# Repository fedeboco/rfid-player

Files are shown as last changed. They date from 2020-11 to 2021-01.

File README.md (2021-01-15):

# RFID Music Player

System that provides an RFID card reader in order to select an album or track in an SD card, avoiding use of buttons or hard to use interfaces for elder people.

- Braille Compatibility.
- Designed for people with advanced age or hearing loss.
- SD Card support. 
- High volume. Volume control.
- Track and album control.
- Easy to setup new RFID cards by custom setup interface.

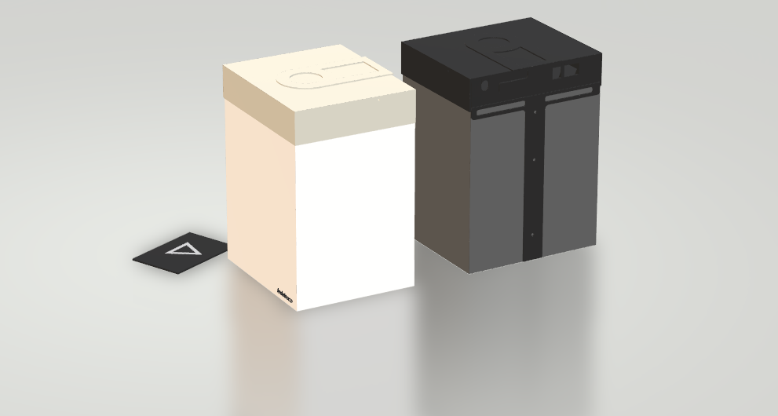
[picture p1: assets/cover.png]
![]()<p align="center">

## PCB

Custom PCB design for hand printing and soldering.
  
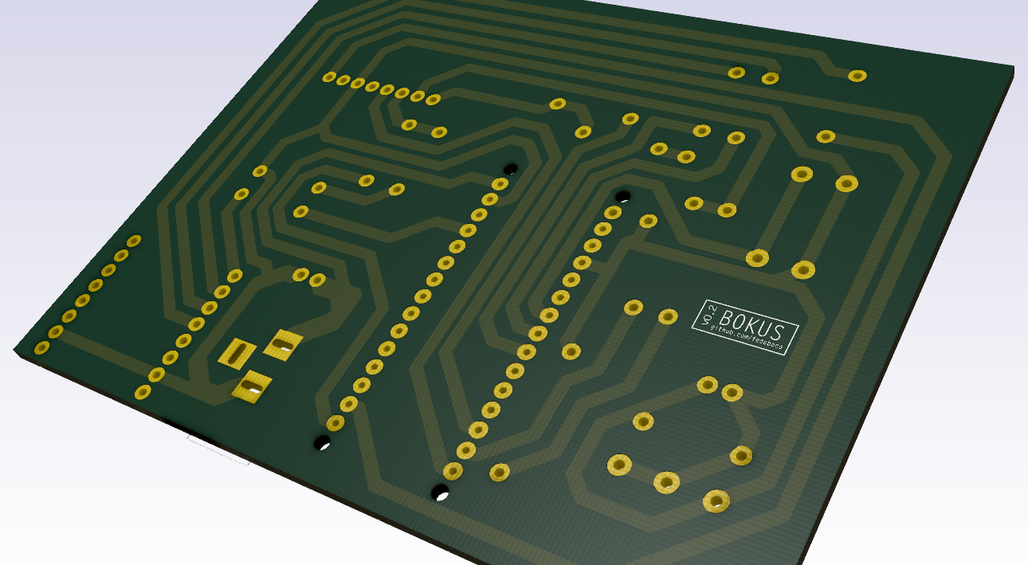
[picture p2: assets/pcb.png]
![]()<p align="center">
  
## Schematic

Custom circuit design.
  
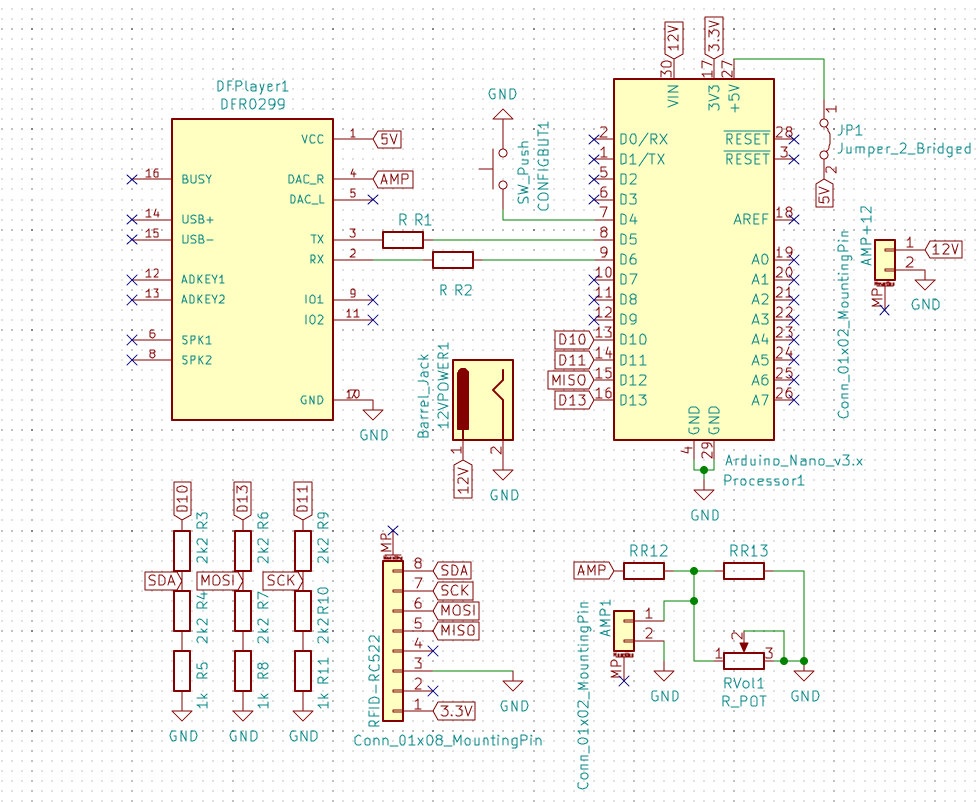
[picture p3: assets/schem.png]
![]()<p align="center">
  
## 3D Parts

Custom 3D printed enclosure for safe circuit install.

### Top
  
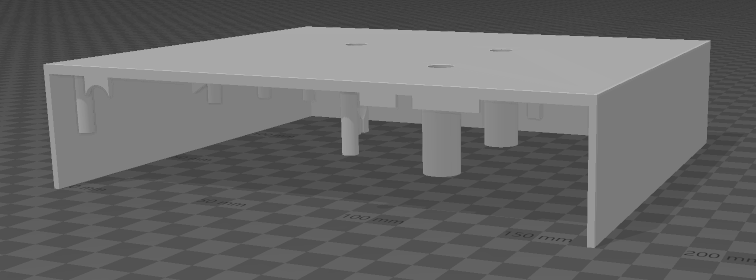
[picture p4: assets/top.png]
![]()<p align="center">
  
### Bot  
  
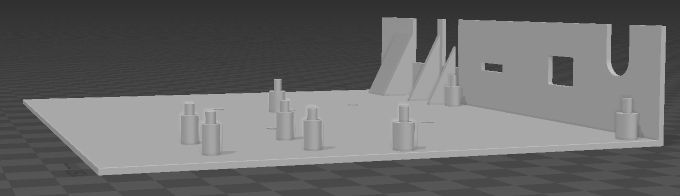
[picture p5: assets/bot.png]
![]()<p align="center">
  
### Back

![]()<p align="center">
  
### Decor

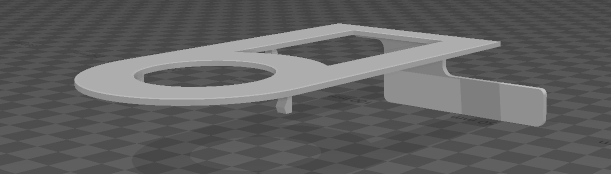
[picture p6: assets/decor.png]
![]()<p align="center">

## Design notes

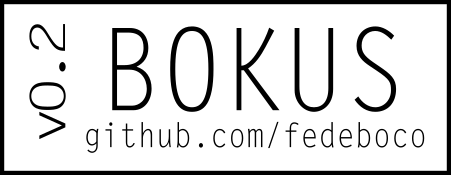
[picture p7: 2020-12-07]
board/rfid-player/label.png

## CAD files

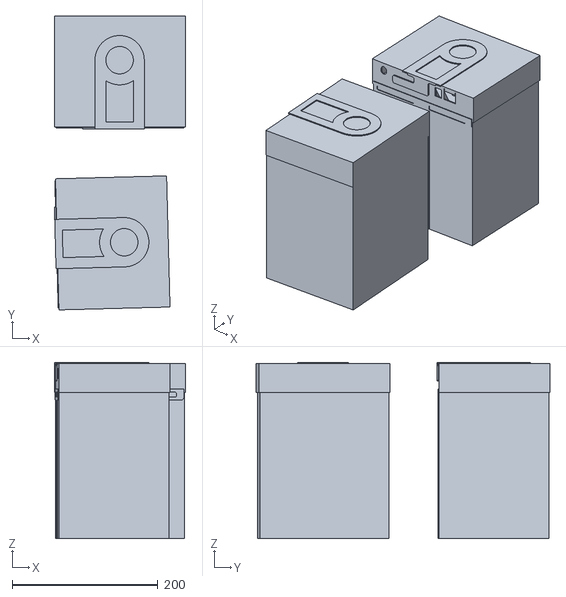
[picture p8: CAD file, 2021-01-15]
stl/complete.stl
180.0 x 403.2 x 241.5

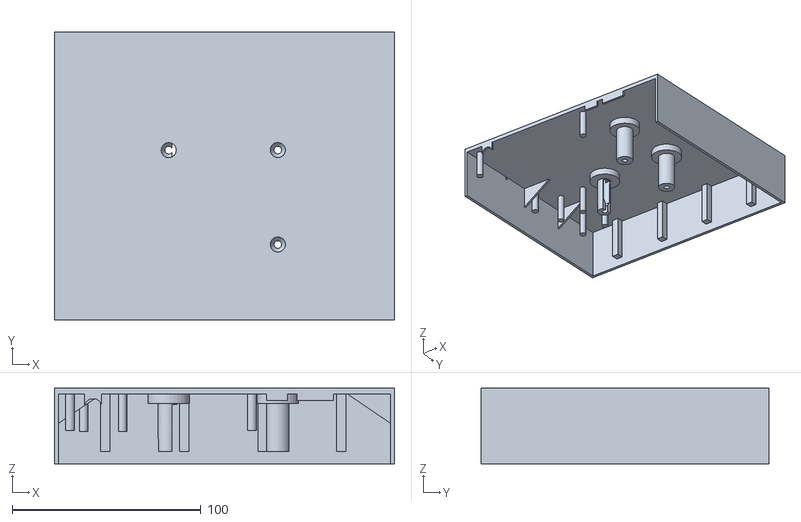
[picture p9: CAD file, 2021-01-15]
stl/top.stl
180.0 x 152.5 x 40.0

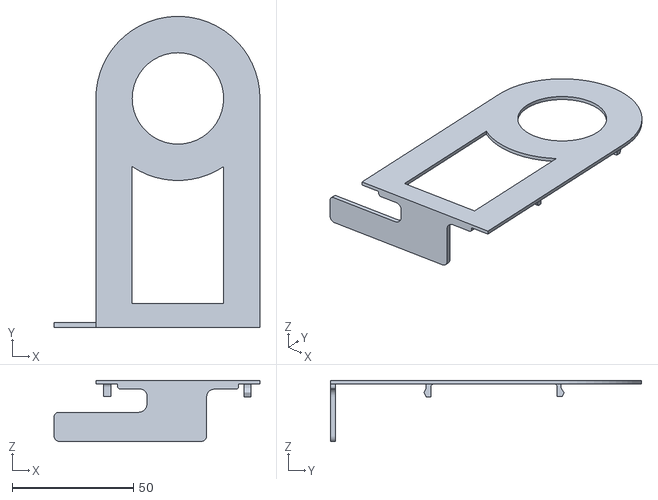
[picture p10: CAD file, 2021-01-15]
stl/decor.stl
85.0 x 128.3 x 25.2

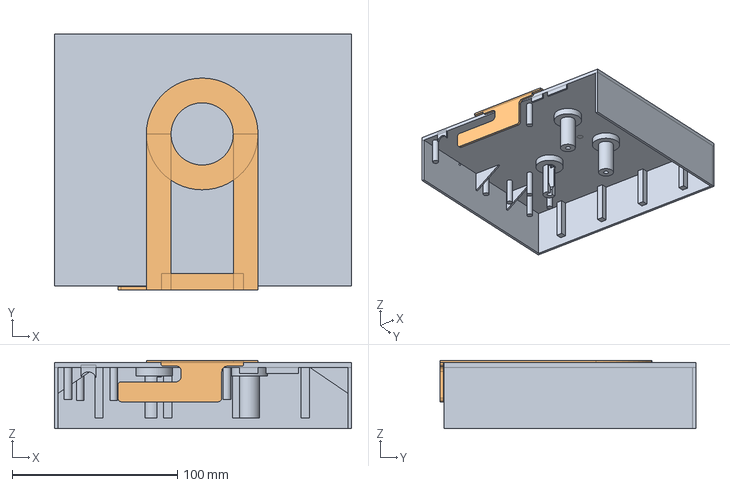
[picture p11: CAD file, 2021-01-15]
stl/topbox.FCStd
180.0 x 155.0 x 41.5 mm
Top
Decor

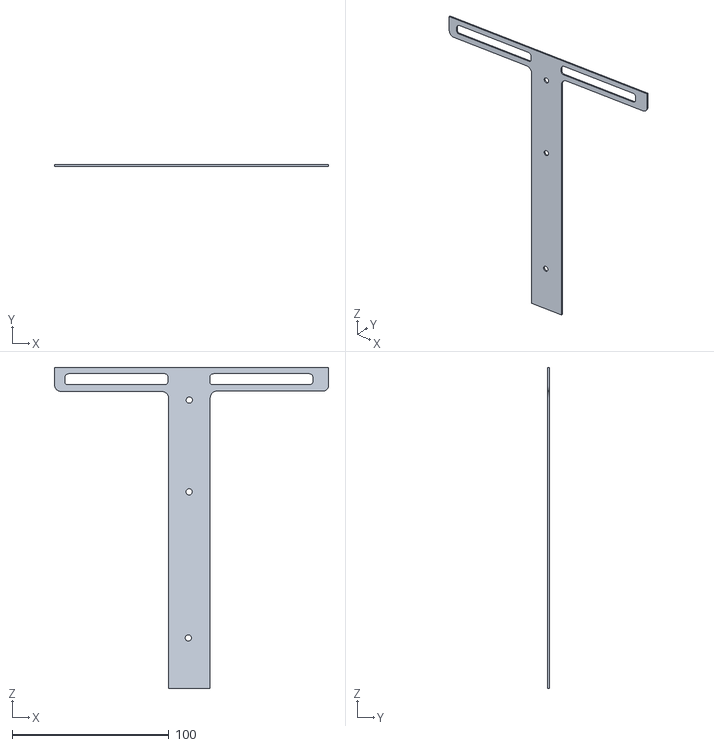
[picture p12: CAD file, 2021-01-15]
stl/back.stl
175.0 x 1.00 x 205.0

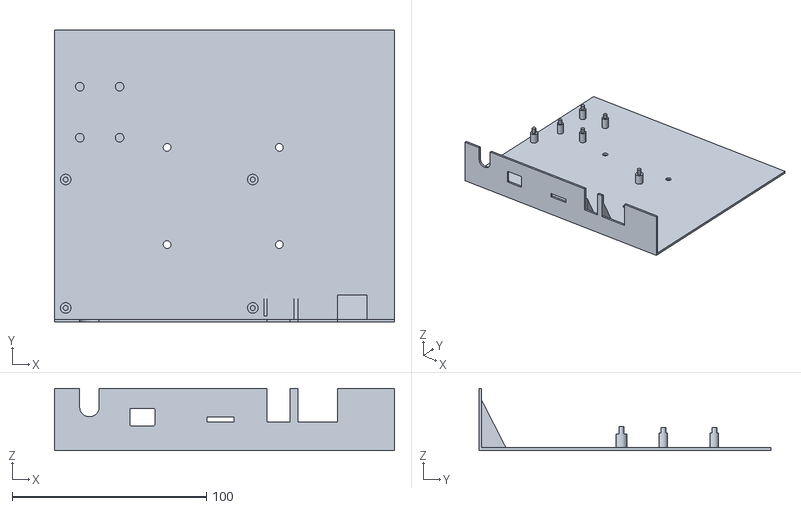
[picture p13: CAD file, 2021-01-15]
stl/bot.stl
175.0 x 150.5 x 32.0

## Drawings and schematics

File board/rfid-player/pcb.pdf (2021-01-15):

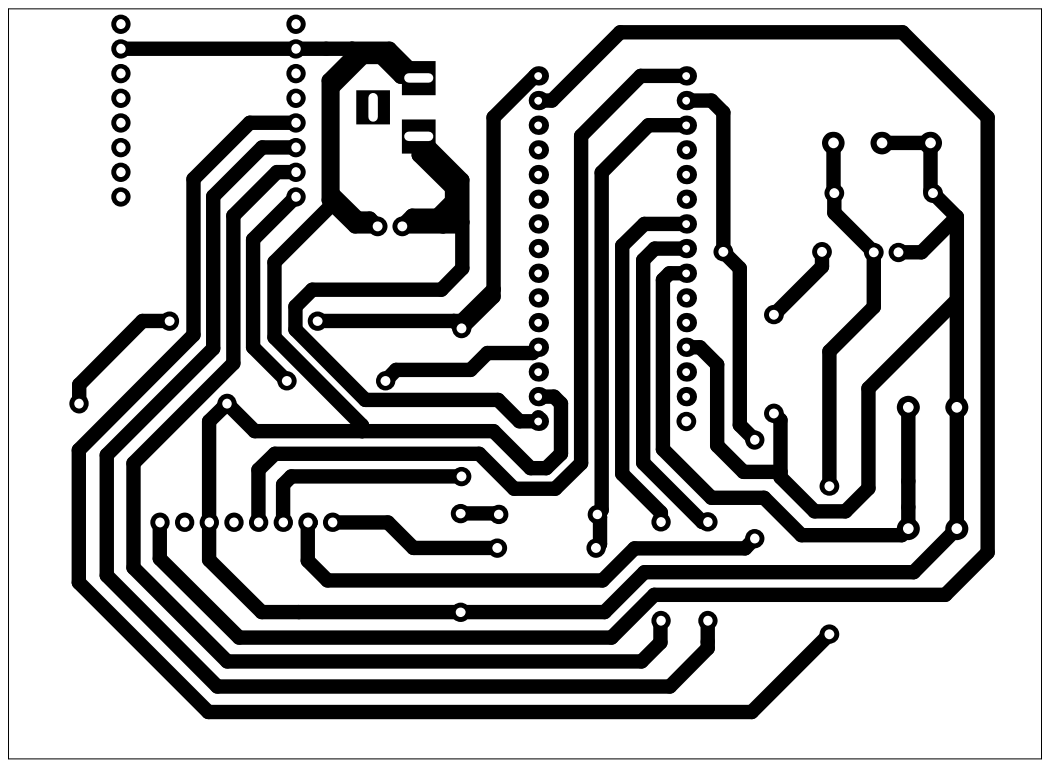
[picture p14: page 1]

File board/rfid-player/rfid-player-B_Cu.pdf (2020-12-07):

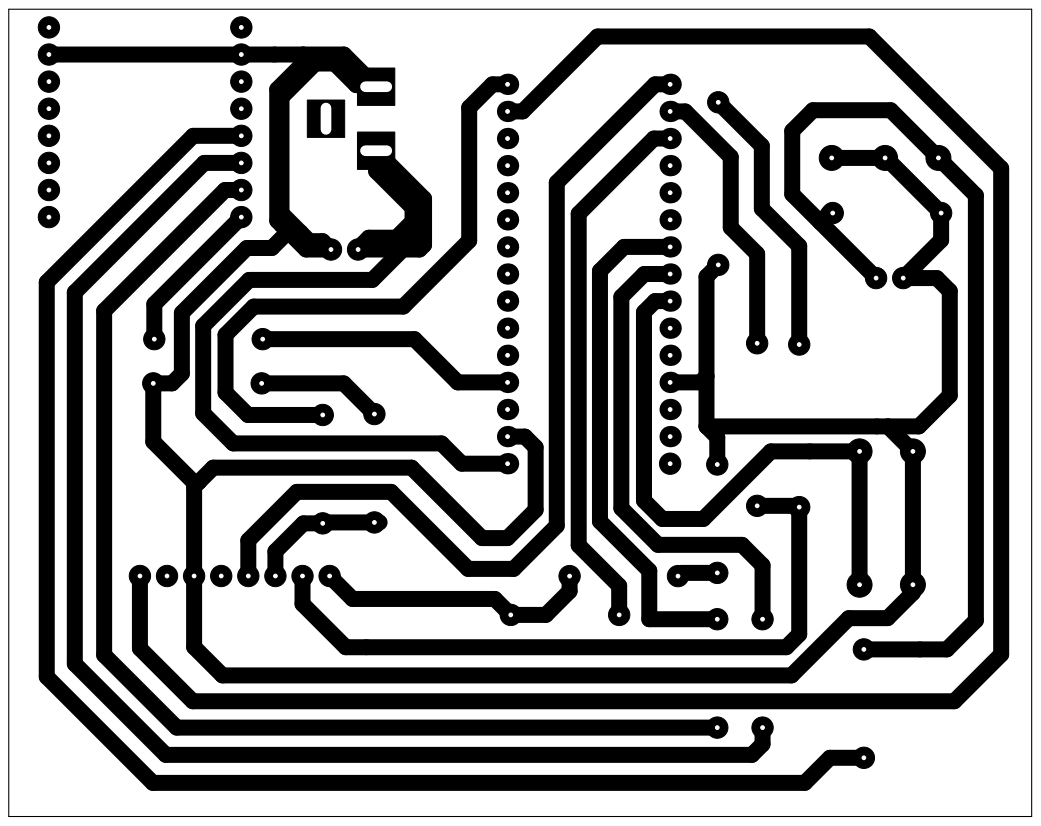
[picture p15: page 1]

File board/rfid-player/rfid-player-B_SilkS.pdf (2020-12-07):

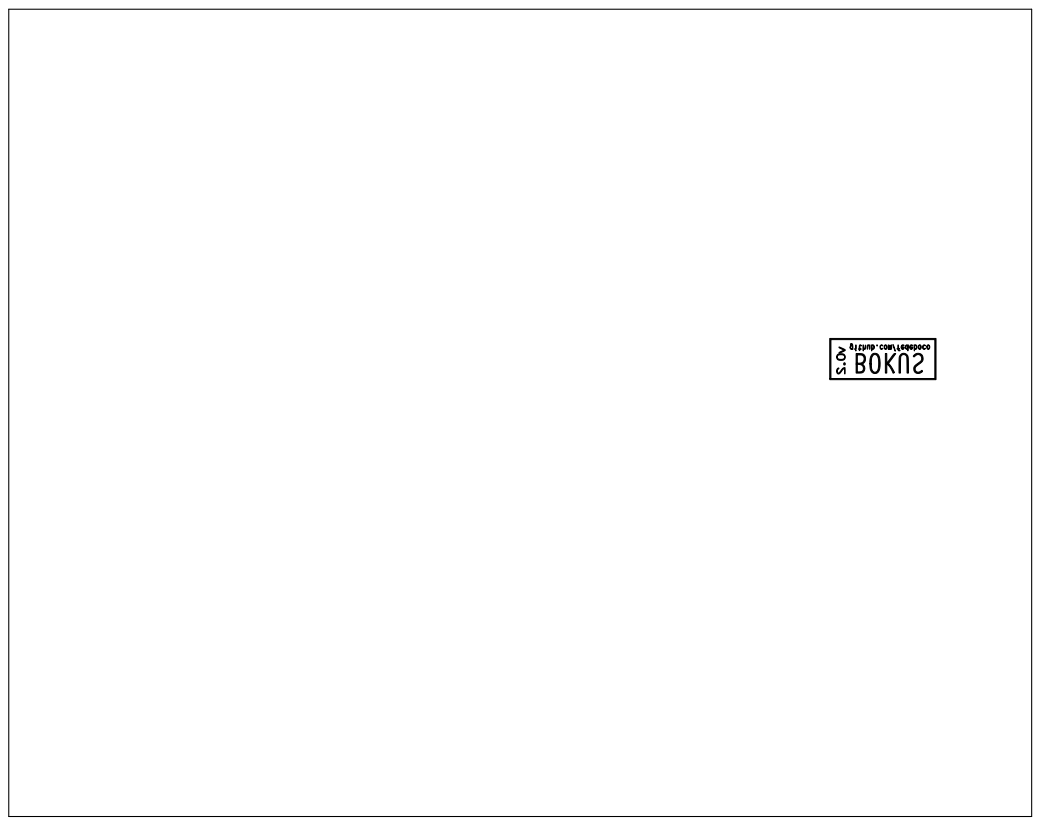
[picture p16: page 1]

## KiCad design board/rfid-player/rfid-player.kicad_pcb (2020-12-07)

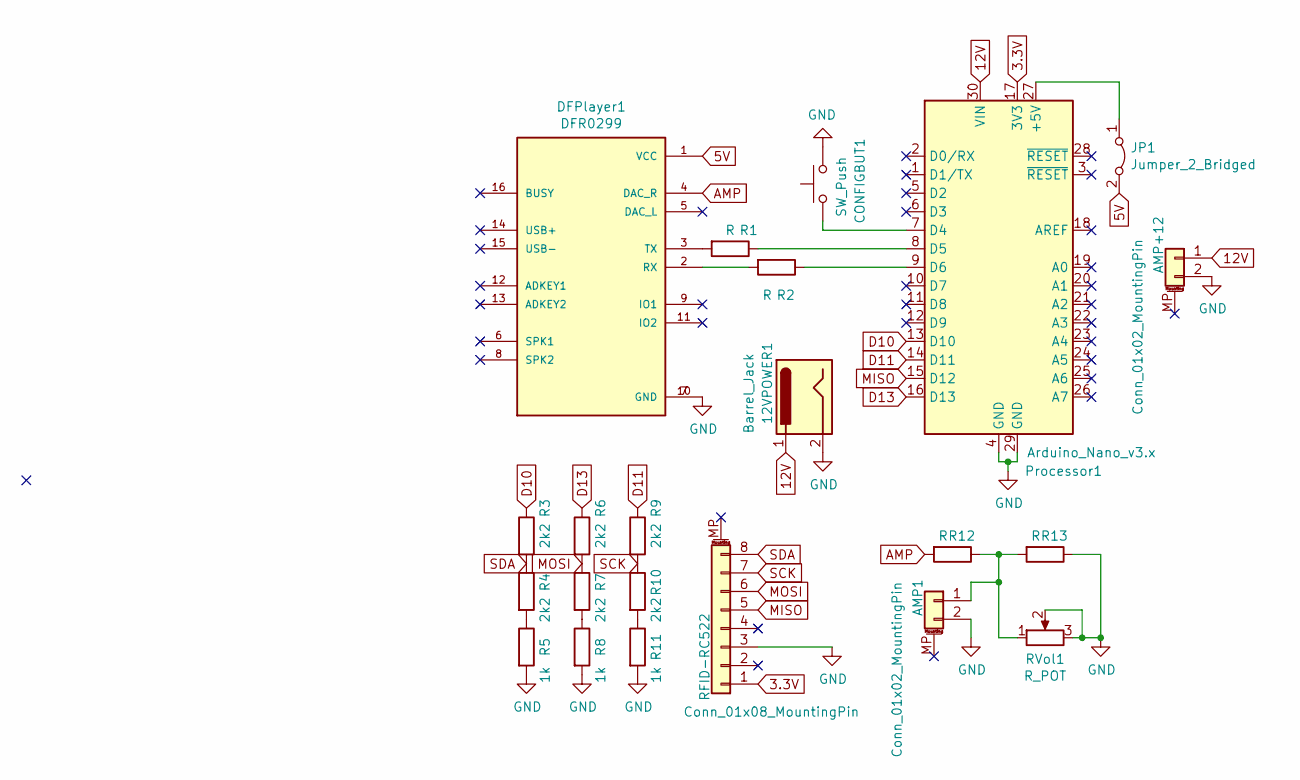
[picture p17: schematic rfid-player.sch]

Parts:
12VPOWER1: Barrel_Jack; BARREL_JACK
AMP1: Conn_01x02_MountingPin; Pin_Header_Straight_1x02_Pitch2.00mm
AMP+12: Conn_01x02_MountingPin; Pin_Header_Straight_1x02_Pitch2.00mm
CONFIGBUT1: SW_Push; SW_PUSH_6mm_h5mm
DFPlayer1: DFR0299; MODULE_DFR0299
JP1: Jumper_2_Bridged; R_Axial_DIN0204_L3.6mm_D1.6mm_P7.62mm_Horizontal
Processor1: Arduino_Nano_v3.x; Arduino_Nano_WithMountingHoles
R1, R2, R12, R13: R; R_Axial_DIN0204_L3.6mm_D1.6mm_P5.08mm_Horizontal
R3, R4, R6, R7, R9, R10: 2k2; R_Axial_DIN0204_L3.6mm_D1.6mm_P5.08mm_Horizontal
R5, R8, R11: 1k; R_Axial_DIN0204_L3.6mm_D1.6mm_P5.08mm_Horizontal
RFID-RC522: Conn_01x08_MountingPin; Pin_Header_Straight_1x08_Pitch2.00mm
RVol1: R_POT; Potentiometer_VishaySpectrol_148_149_Single_Horizontal

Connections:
3.3V: Processor1.17 (3V3), RFID-RC522.1
5V: DFPlayer1.1 (VCC), JP1.2 (B)
12V: 12VPOWER1.1, AMP+12.1, Processor1.30 (VIN)
AMP: DFPlayer1.4 (DAC_R), R12.2
D10: Processor1.13 (D10), R3.1
D11: Processor1.14 (D11), R9.1
D13: Processor1.16 (D13), R6.1
GND: 12VPOWER1.2, AMP1.2, AMP+12.2, CONFIGBUT1.2, DFPlayer1.7 (GND), DFPlayer1.10 (GND), Processor1.4 (GND), Processor1.29 (GND), R5.2, R8.2, R11.2, R13.1, RFID-RC522.3, RVol1.2, RVol1.3
MISO: Processor1.15 (D12), RFID-RC522.5
MOSI: R6.2, R7.1, RFID-RC522.6
unnamed: AMP1.1, R12.1, R13.2, RVol1.1
unnamed: CONFIGBUT1.1, Processor1.7 (D4)
unnamed: DFPlayer1.2 (RX), R2.2
unnamed: DFPlayer1.3 (TX), R1.2
unnamed: JP1.1 (A), Processor1.27 (+5V)
unnamed: Processor1.8 (D5), R1.1
unnamed: Processor1.9 (D6), R2.1
unnamed: R4.2, R5.1
unnamed: R7.2, R8.1
unnamed: R10.2, R11.1
SCK: R9.2, R10.1, RFID-RC522.7
SDA: R3.2, R4.1, RFID-RC522.8

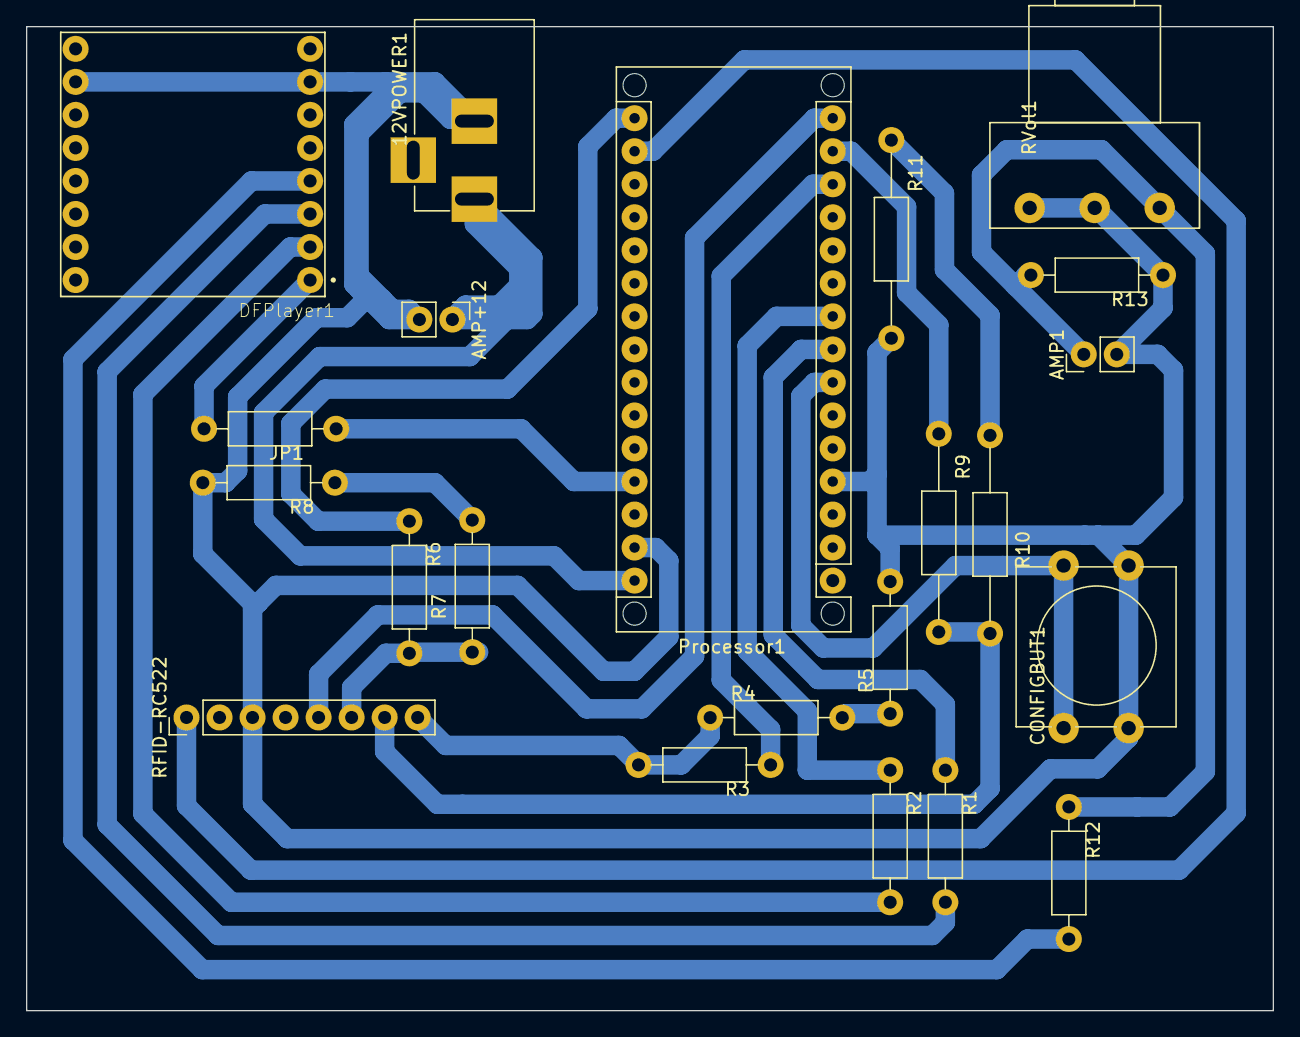
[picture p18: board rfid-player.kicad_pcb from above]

Board: 2 copper layers, 95.9 x 75.7 mm, 22 parts (0 on the bottom side), 22 nets.

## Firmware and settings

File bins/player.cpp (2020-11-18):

#include "player.h"
#include "SoftwareSerial.h"

Player::Player(int rx, int tx, int folders) : 
                mySoftwareSerial{SoftwareSerial(rx,tx)}, 
                timer{millis()},
                folders{folders} {
}

int Player::getFolders() {
    return folders;
}

void Player::start() {
    mySoftwareSerial.begin(BAUD_RATE);
    Serial.println();
    Serial.println(F(DFSTARTUP));

    // second boolean forces restart and pops speaker
    while (!myDFPlayer.begin(mySoftwareSerial, true, true)) {
        delay(DFRECONNECT_DELAY);
        Serial.println(F(DF_NOT_DETECTED));
    }
    Serial.println(F(DF_CONNECTED));
    currentFolderTracks = -1;
    while (currentFolderTracks == -1) {
        delay(DFRECONNECT_DELAY);
        currentFolderTracks = myDFPlayer.readFileCountsInFolder(1);
    };
    setDFOptions();
}

void Player::setDFOptions() {
    myDFPlayer.setTimeOut(DFTIMEOUT);
    myDFPlayer.EQ(DFPLAYER_EQ_NORMAL);
    myDFPlayer.outputDevice(DFPLAYER_DEVICE_SD);
    myDFPlayer.volume(VOLUME); //0 to 30
}

int Player::numberOfFolders() {
    return myDFPlayer.readFolderCounts();
}

void Player::MP3Folder(int fileNumber) {
    myDFPlayer.playMp3Folder(fileNumber);
    delay(DFRECONNECT_DELAY);
}

void Player::translateCard(int index){
    if (index == folders + 1) {
        cardType = PLAY;
    } else if (index == folders + 2) {
        cardType = NEXT;
    } else if (index <= folders) {
        cardType = FOLDER;
        folderPlaying = index;
    } else {
        cardType = INVALID;
    }
}

int Player::countFolderFiles(int index) {
    return myDFPlayer.readFileCountsInFolder(index);
}

// asumes device turns on in folder 1
void Player::next() {
    Serial.print("Tracks:");
    Serial.println(currentFolderTracks);
    if (currentTrack == currentFolderTracks) {
        currentTrack = 1;
        myDFPlayer.loopFolder(folderPlaying);
    } else {
        currentTrack++;
        myDFPlayer.next();
    }
    playing = true;
}

void Player::play() {
    if (playing == true)
        myDFPlayer.pause();
    else
        myDFPlayer.start();
    playing = !playing;
}

void Player::folder() {
    currentTrack = 1;
    currentFolderTracks = countFolderFiles(folderPlaying);
    myDFPlayer.loopFolder(folderPlaying);
}

void Player::processPlayer(String card, bool updatedCard) {
    if (updatedCard) {
        if (cardType == NEXT) {
            next();
        } else if (cardType == PLAY) {
            play();
        } else if (cardType == FOLDER) {
            folder();
        } else {
            Serial.println(INVALID_CARD);
        }

        if (myDFPlayer.available())
            handleDFState(myDFPlayer.readType(), myDFPlayer.read());
    }
}

 // Print the detail message from DFPlayer to handle 
 // different errors and states.
void Player::handleDFState(uint8_t type, int value) {
    Serial.println(type);
    switch (type) {
        case TimeOut:
        Serial.println(F("Time Out!"));
        break;
        case WrongStack:
        Serial.println(F("Stack Wrong!"));
        break;
        case DFPlayerCardInserted:
        Serial.println(F("Card Inserted!"));
        break;
        case DFPlayerCardRemoved:
        Serial.println(F("Card Removed!"));
        break;
        case DFPlayerCardOnline:
        Serial.println(F("Card Online!"));
        break;
        case DFPlayerPlayFinished:
        Serial.print(F("Number:"));
        Serial.print(value);
        Serial.println(F(" Play Finished!"));
        break;
        case DFPlayerError:
        Serial.print(F("DFPlayerError:"));
        switch (value) {
            case Busy:
            Serial.println(F("Card not found"));
            break;
            case Sleeping:
            Serial.println(F("Sleeping"));
            break;
            case SerialWrongStack:
            Serial.println(F("Get Wrong Stack"));
            break;
            case CheckSumNotMatch:
            Serial.println(F("Check Sum Not Match"));
            break;
            case FileIndexOut:
            Serial.println(F("File Index Out of Bound"));
            break;
            case FileMismatch:
            Serial.println(F("Cannot Find File"));
            break;
            case Advertise:
            Serial.println(F("In Advertise"));
            break;
            default:
            break;
        }
        break;
        default:
        break;
    }
}

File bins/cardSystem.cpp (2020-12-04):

#include "cardSystem.h"

CardSystem::CardSystem() :
                        card{Card(SS_PIN, RST_PIN)},   // Create MFRC522 instance.
                        config{Config(BUTTON_PIN)},
                        player{Player(RX_DF_PIN, TX_DF_PIN, config.readFoldersEEPROM())} {

}

void CardSystem::updateSystem() {
    bool newCard = card.processCard();
    if (newCard)
        updateCardType(findCard(card.getCard()));
    player.processPlayer(card.getCard(), card.isNewCard());
    newCard ? delay(CARD_READ_DELAY) : delay(NO_NEW_CARD_DELAY);
}

//first bytes for general config
void CardSystem::saveCardsToEEPROM(int pendingCards) {
    Serial.println(pendingCards);
    config.writeFoldersEEPROM(pendingCards - ACTIONS); //number of folders
    for (int i = 0; pendingCards > 0; i++, pendingCards--) {

        if (pendingCards == ACTIONS) {
            player.MP3Folder(MAX_CARDS + 1);
        } else if (pendingCards == ACTIONS - 1) {
            player.MP3Folder(MAX_CARDS + 2);
        } else {
            player.MP3Folder(i + 1);
        }
        
        while(!card.isNewCard()){
            card.processCard();
            delay(CARD_CHECK_EEPROM_DELAY);
        }

        // ignores if already exists in current save
        if ( i == 0 || (findCard(card.getCard(), 1, i) == -1) ) {
            config.writeEEPROM(card.getCard(), i + 1);
        } else {
            i--;
            pendingCards++;
        }
    }
}

// returns index if found, -1 otherwise
int CardSystem::findCard(String card) {
    int i = 1;
    String candidate;

    while (i <= player.getFolders() + ACTIONS) {
        if (config.readEEPROM(i) == card.substring(1))
            return i;
        i++;
    }
    return -1;
}

int CardSystem::findCard(String card, int start, int end) {
    int i = start;
    String candidate;

    while (i <= end) {
        if (config.readEEPROM(i) == card.substring(1))
            return i;
        i++;
    }
    return -1;
}

void CardSystem::updateCardType(int index) {
    player.translateCard(index);
}

void CardSystem::printCardsFromEEPROM(int cardsNumber) {
    Serial.println(cardsNumber);

    for (int i = 0; i < cardsNumber; i++) {
        Serial.println(config.readEEPROM(i + 1));
    }
}

void CardSystem::initCardConfig() {
    int pendingCards = -1;

    player.start();
    // takes some time to update folders
    while (pendingCards == -1){
        pendingCards = player.numberOfFolders();
        delay(1000);
    }

    pendingCards + ACTIONS - 1; // +2 (play and next) -1 (MP3 folder)
    saveCardsToEEPROM(pendingCards);
}

void CardSystem::init() {
    card.init();
    Serial.begin(115200);

    if(config.readButton()){
        initCardConfig();
    } else {
        player.start();
    } 
}

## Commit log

2020-12-04 PCB Schematic and plot
    [rfid-player.kicad_pcb, rfid-player.sch]
2020-12-07 Board fixes
    [rfid-player.kicad_pcb, rfid-player.sch]
2020-12-07 fixed wrong resistor layout. logo inserted. reduced size.
    [rfid-player.kicad_pcb]
2020-12-07 Added PCB PDF
2021-01-15 added 3D files
    [back.stl, bot.stl, decor.stl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]
2021-01-15 assets for readme
    [complete.stl]
